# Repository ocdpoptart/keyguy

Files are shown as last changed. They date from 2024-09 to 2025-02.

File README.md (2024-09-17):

This entire thing has been a project to make a keyboard that had every quality I liked in one except for having a usb hub (I figured I could make one of those later). Unfortunately this entire thing has spiraled out of control and now I have even learned how to use this silly thing called GitHub. I want to cry.

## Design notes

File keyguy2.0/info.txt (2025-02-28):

so after taking forever to finish the keyboard you succeeded

now the issue is that it was flawed from the start now onto the changes

X (wrong from the start only needed to change the pin) - first a different oled (this is because the nice view steals the rgb pin) [there is an example of this in your saved bookmarks]
X - next change the led tolerances because depending on the saulder job the keys can hit them (push them up like half a mil)
X - maybe add more with use of the keyboard get used to it and if there are complaints then they can be corrected for v2
- I like the height of the overall product as it is in v1, so raise just the outer walls of the case no need to change the thickness of bottom plate or the height of the standoffs, this raised outer wall will allow the plate to fit in snug and not be a nuicense while protecting the board more (this will force you to have to make case cutouts for the usbc port and the pwr/rst switch, hurray blender or freecad) [18mm height for the outer wall]
-

COMPLETELY UNUSABLE ACCIDENTLY WIRED 4 KEYS EXACTLY THE SAME LIKE AN IDIOT

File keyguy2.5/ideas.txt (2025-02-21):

IDEAS:
    -holes/space for screen niceview screen protector
    -depending on how you like the 2.0 case possibly make adjustments to allow fit with the screen protector (and better protection of keys and pcb) [you also bought batteries too big for the case so if you don't like the case size which you may not you can adjust to accomadate them]

TO ADD:

DONE:
    - change mounting hole sizes from m2.5 to m2
    - correct the led matrix so that they are all connected to the pin and work properly made that mistake again with these fucking leds

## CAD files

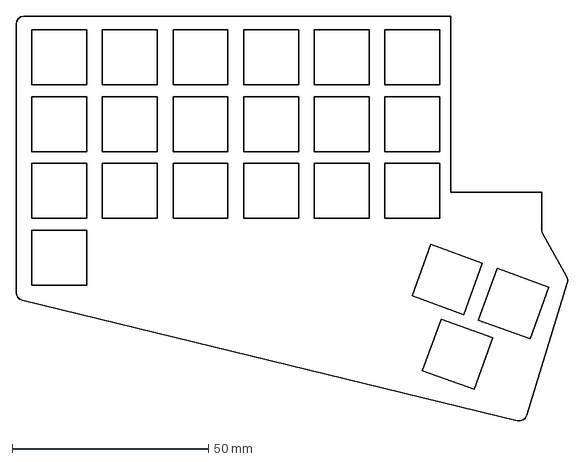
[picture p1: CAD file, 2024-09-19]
keyguy2.0/output/outlines/xlboard_cutout.dxf
140.6 x 103.3 mm

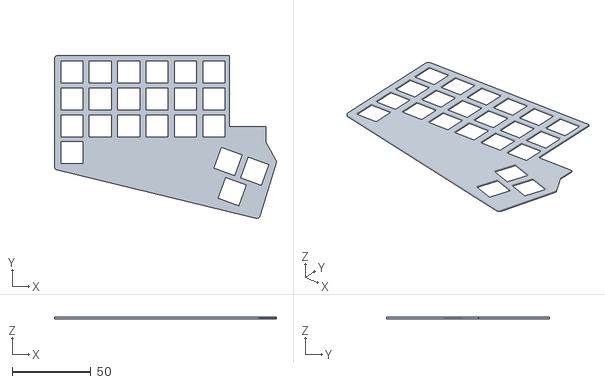
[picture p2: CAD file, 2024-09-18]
v3all/goodplate2.stl
140.6 x 103.1 x 1.00

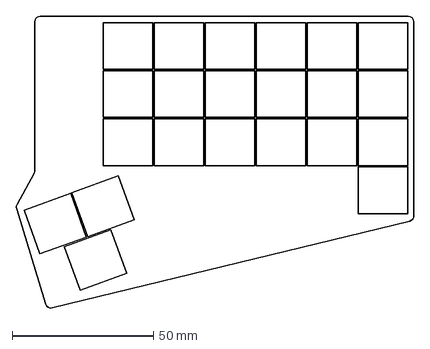
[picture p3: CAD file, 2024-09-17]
v3all/output/outlines/xlboard_cutout2.dxf
140.6 x 103.3 mm

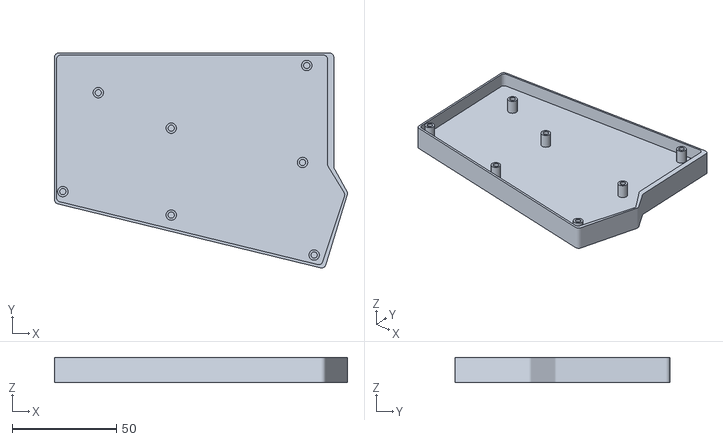
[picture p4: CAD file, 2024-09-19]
v4all/case.stl
140.6 x 103.1 x 12.0

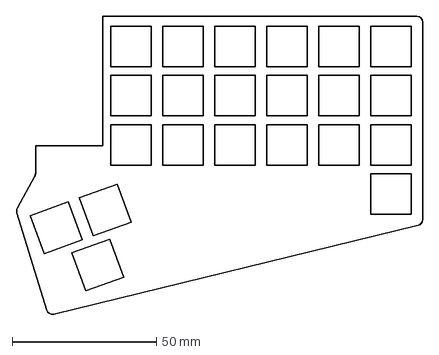
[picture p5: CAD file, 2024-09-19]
keyguy2.0/output/outlines/xlboard2_cutout.dxf
140.6 x 103.3 mm

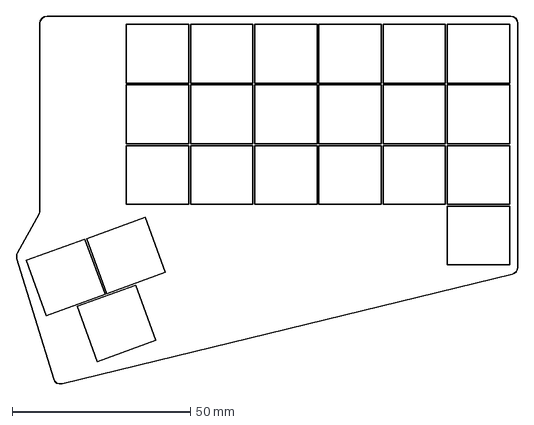
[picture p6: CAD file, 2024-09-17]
v2all/outlines/xlboard_cutout2.dxf
140.6 x 103.3 mm

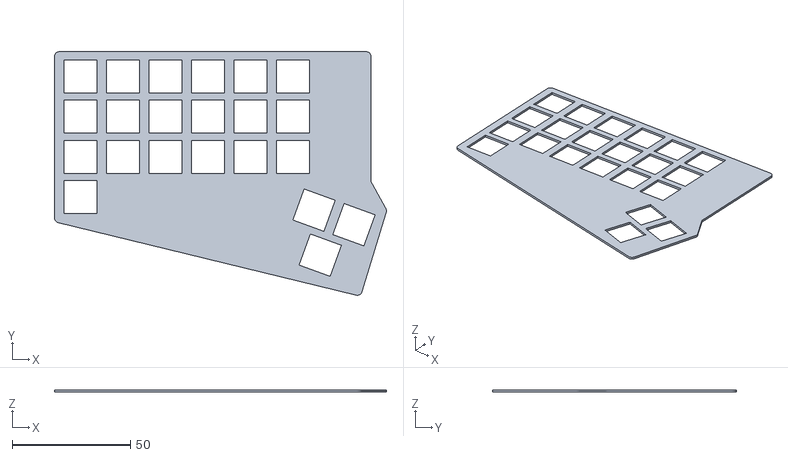
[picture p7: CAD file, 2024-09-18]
v3all/goodplate.stl
140.6 x 103.1 x 1.00

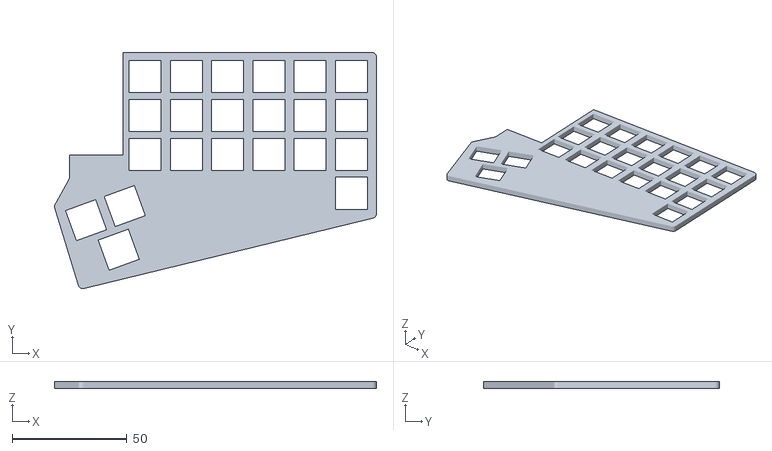
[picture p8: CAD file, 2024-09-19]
v4all/plate2.stl
140.6 x 103.1 x 3.00

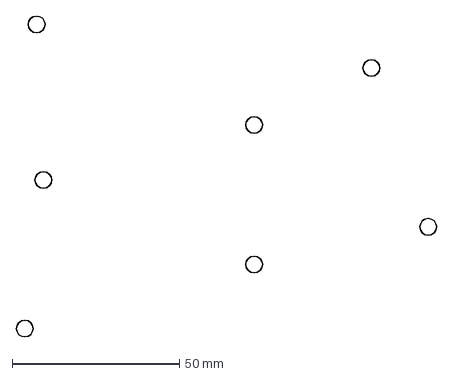
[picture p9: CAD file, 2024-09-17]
keyguy2.0/output/outlines/standoff2.dxf
125.6 x 95.9 mm

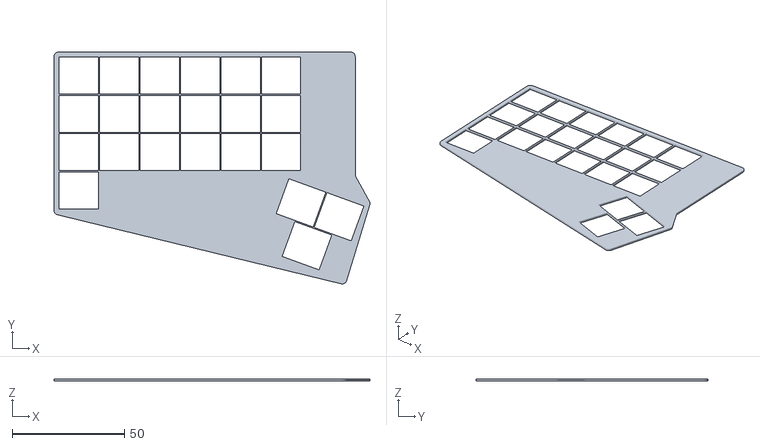
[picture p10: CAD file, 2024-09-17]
v3all/plate.stl
140.6 x 103.1 x 1.00

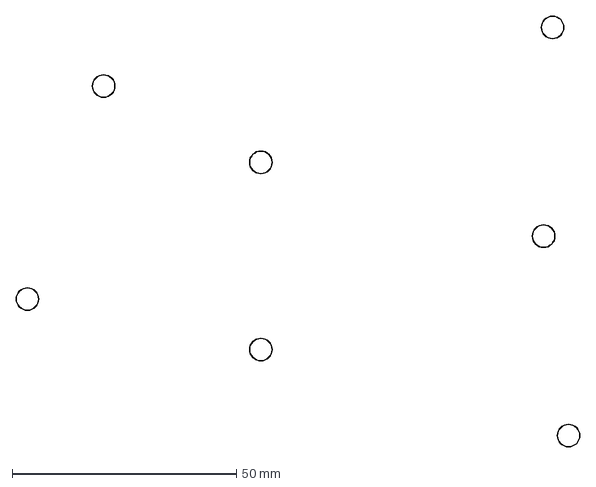
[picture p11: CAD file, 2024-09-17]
keyguy2.0/output/outlines/standoff.dxf
125.6 x 95.9 mm

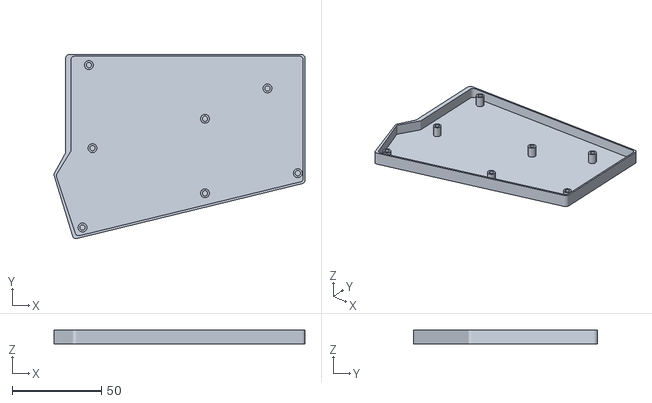
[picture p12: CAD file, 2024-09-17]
v3all/case2.stl
140.6 x 103.1 x 8.00

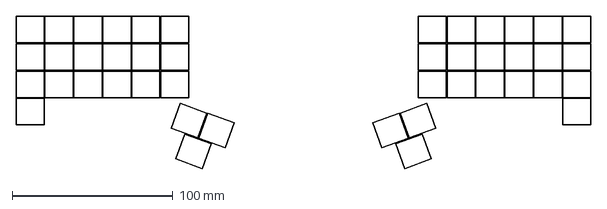
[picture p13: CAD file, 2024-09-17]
keyguy2.0/output/outlines/keys.dxf
357.5 x 94.6 mm

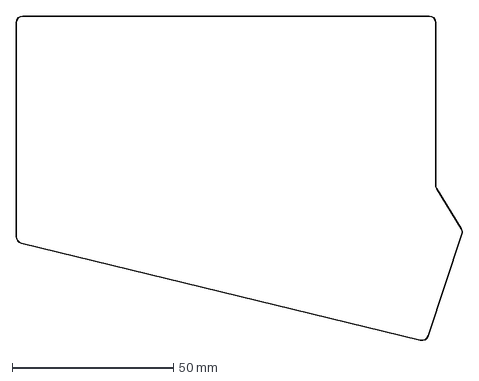
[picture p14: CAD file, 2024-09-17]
keyguy2.0/output/outlines/board.dxf
138.3 x 100.7 mm

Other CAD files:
v4all/case2.stl
v4all/plate.stl
v3all/case.stl
keyguy2.0/output/outlines/combo.dxf
keyguy2.0/output/outlines/board2.dxf
keyguy2.0/output/outlines/combo2.dxf
keyguy2.0/output/outlines/mounting.dxf
keyguy2.0/output/outlines/mounting2.dxf
keyguy2.0/output/outlines/raw.dxf
keyguy2.0/output/outlines/xlboard.dxf
keyguy2.0/output/outlines/xlboard2.dxf
v1outlines/board.dxf
v1outlines/combo.dxf
v1outlines/keys.dxf
v1outlines/raw.dxf
v2all/outlines/board.dxf
v2all/outlines/board2.dxf
v2all/outlines/combo.dxf
v2all/outlines/combo2.dxf
v2all/outlines/keys.dxf
v2all/outlines/mounting.dxf
v2all/outlines/mounting2.dxf
v2all/outlines/raw.dxf
v2all/outlines/standoff.dxf
v2all/outlines/standoff2.dxf
v2all/outlines/xlboard.dxf
v2all/outlines/xlboard2.dxf
v2all/outlines/xlboard_cutout.dxf

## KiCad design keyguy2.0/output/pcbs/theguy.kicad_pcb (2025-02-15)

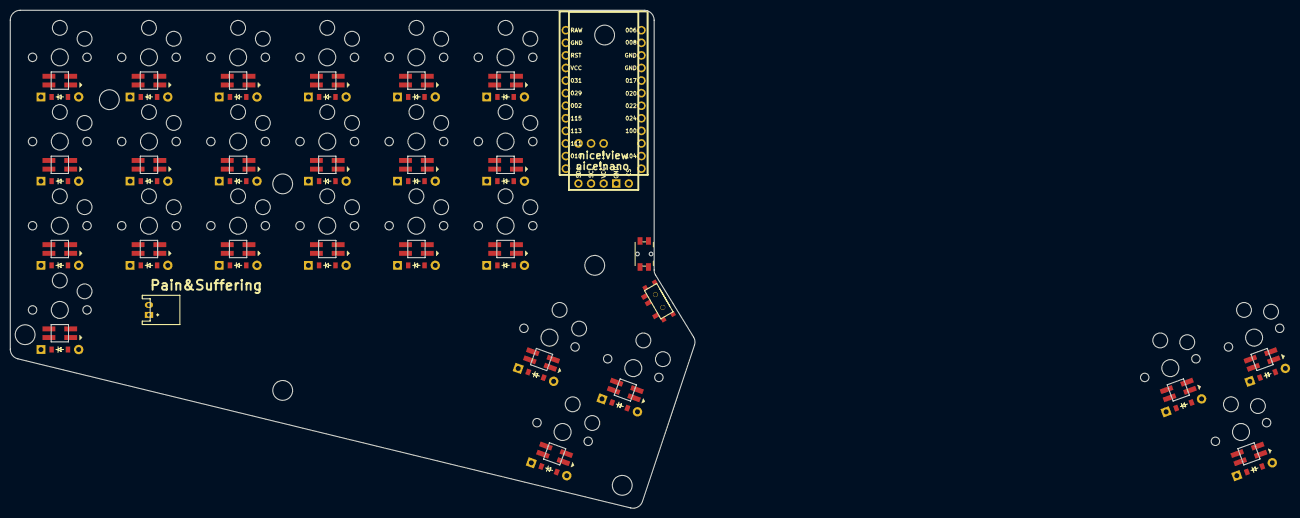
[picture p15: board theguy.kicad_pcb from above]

Board: 2 copper layers, 138.2 x 100.5 mm, 80 parts (0 on the bottom side), 64 nets, no tracks yet.

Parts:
B1: Panasonic_EVQPUL_EVQPUC
D1, D2, D3, D4, D5, D6, D7, D8, D9, D10, D11, D12, D13, D14, D15, D16, D17, D18, D19, D20, D21, D22, D23, D24, D25: ComboDiode
JST1: JST_PH_S2B-PH-K_02x2.00mm_Angled
LED1, LED2, LED3, LED4, LED5, LED6, LED7, LED8, LED9, LED10, LED11, LED12, LED13, LED14, LED15, LED16, LED17, LED18, LED19, LED20, LED21, LED22, LED23, LED24, LED25: WS2812B
MCU1: nice_nano
S1, S2, S3, S4, S5, S6, S7, S8, S9, S10, S11, S12, S13, S14, S15, S16, S17, S18, S19, S20, S21, S22, S23, S24, S25: PG1350
T1: SPDT_C128955
niceView1: niceView; niceView_headers

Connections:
GND: B1.1, JST1.2, LED1.3, LED2.3, LED3.3, LED4.3, LED5.3, LED6.3, LED7.3, LED8.3, LED9.3, LED10.3, LED11.3, LED12.3, LED13.3, LED14.3, LED15.3, LED16.3, LED17.3, LED18.3, LED19.3, LED20.3, LED21.3, LED22.3, LED23.3, LED24.3, LED25.3, MCU1.3, MCU1.4, MCU1.23, niceView1.2
P002: MCU1.18, S8.1, S9.1, S10.1
P006: LED22.4, LED25.4, MCU1.1
P009: D3.1, D6.1, D9.1, D12.1, D15.1, D18.1, MCU1.13
P010: D4.1, D7.1, D10.1, D13.1, D16.1, D19.1, MCU1.14
P017: MCU1.5, niceView1.5
P020: MCU1.6, niceView1.4
P022: MCU1.7, niceView1.1
P029: MCU1.19, S5.1, S6.1, S7.1
P031: MCU1.20, S1.1, S2.1, S3.1, S4.1
P104: D2.1, D5.1, D8.1, D11.1, D14.1, D17.1, D20.1, D21.1, D23.1, D24.1, MCU1.11
P106: D1.1, D22.1, D25.1, MCU1.12
P111: MCU1.15, S17.1, S18.1, S19.1, S21.1, S22.1, S24.1, S25.1
P113: MCU1.16, S14.1, S15.1, S16.1, S20.1, S23.1
P115: MCU1.17, S11.1, S12.1, S13.1
RAW: MCU1.24, T1.2
RST: B1.2, MCU1.22
VCC: LED1.1, LED2.1, LED3.1, LED4.1, LED5.1, LED6.1, LED7.1, LED8.1, LED9.1, LED10.1, LED11.1, LED12.1, LED13.1, LED14.1, LED15.1, LED16.1, LED17.1, LED18.1, LED19.1, LED20.1, LED21.1, LED22.1, LED23.1, LED24.1, LED25.1, MCU1.21, niceView1.3
extra_cluster: D22.2, S22.2
hell_bottom: D2.2, S2.2
hell_home: D3.2, S3.2
hell_last: D1.2, S1.2
hell_top: D4.2, S4.2
index_bottom: D14.2, S14.2
index_home: D15.2, S15.2
index_top: D16.2, S16.2
inner_bottom: D17.2, S17.2
inner_home: D18.2, S18.2
inner_top: D19.2, S19.2
layer_cluster: D20.2, S20.2
middle_bottom: D11.2, S11.2
middle_home: D12.2, S12.2
middle_top: D13.2, S13.2
mirror_extra_cluster: D25.2, S25.2
mirror_layer_cluster: D23.2, S23.2
mirror_space_cluster: D24.2, S24.2
pinky_bottom: D5.2, S5.2
pinky_home: D6.2, S6.2
pinky_top: D7.2, S7.2
pos: JST1.1, T1.1
rgb_matrix_hell_bottom: LED2.4, LED3.2
rgb_matrix_hell_home: LED3.4, LED4.2
rgb_matrix_hell_last: LED1.4, LED2.2
rgb_matrix_hell_top: LED4.4, LED7.2
rgb_matrix_index_bottom: LED14.4, LED15.2, LED20.2, LED23.2
rgb_matrix_index_home: LED15.4, LED16.2
rgb_matrix_index_top: LED16.4, LED19.2
rgb_matrix_inner_bottom: LED17.4, LED22.2, LED25.2
rgb_matrix_inner_home: LED17.2, LED18.4
rgb_matrix_inner_top: LED18.2, LED19.4
rgb_matrix_middle_home: LED11.2, LED12.4
rgb_matrix_middle_top: LED12.2, LED13.4
rgb_matrix_pinky_bottom: LED5.4, LED8.2
rgb_matrix_pinky_home: LED5.2, LED6.4
rgb_matrix_pinky_top: LED6.2, LED7.4
rgb_matrix_ring_bottom: LED8.4, LED9.2
rgb_matrix_ring_home: LED9.4, LED10.2
rgb_matrix_ring_top: LED10.4, LED13.2
rgb_thumbs_layer_cluster: LED20.4, LED21.2, LED23.4, LED24.2
rgb_thumbs_space_cluster: LED14.2, LED21.4, LED24.4
ring_bottom: D8.2, S8.2
ring_home: D9.2, S9.2
ring_top: D10.2, S10.2
space_cluster: D21.2, S21.2

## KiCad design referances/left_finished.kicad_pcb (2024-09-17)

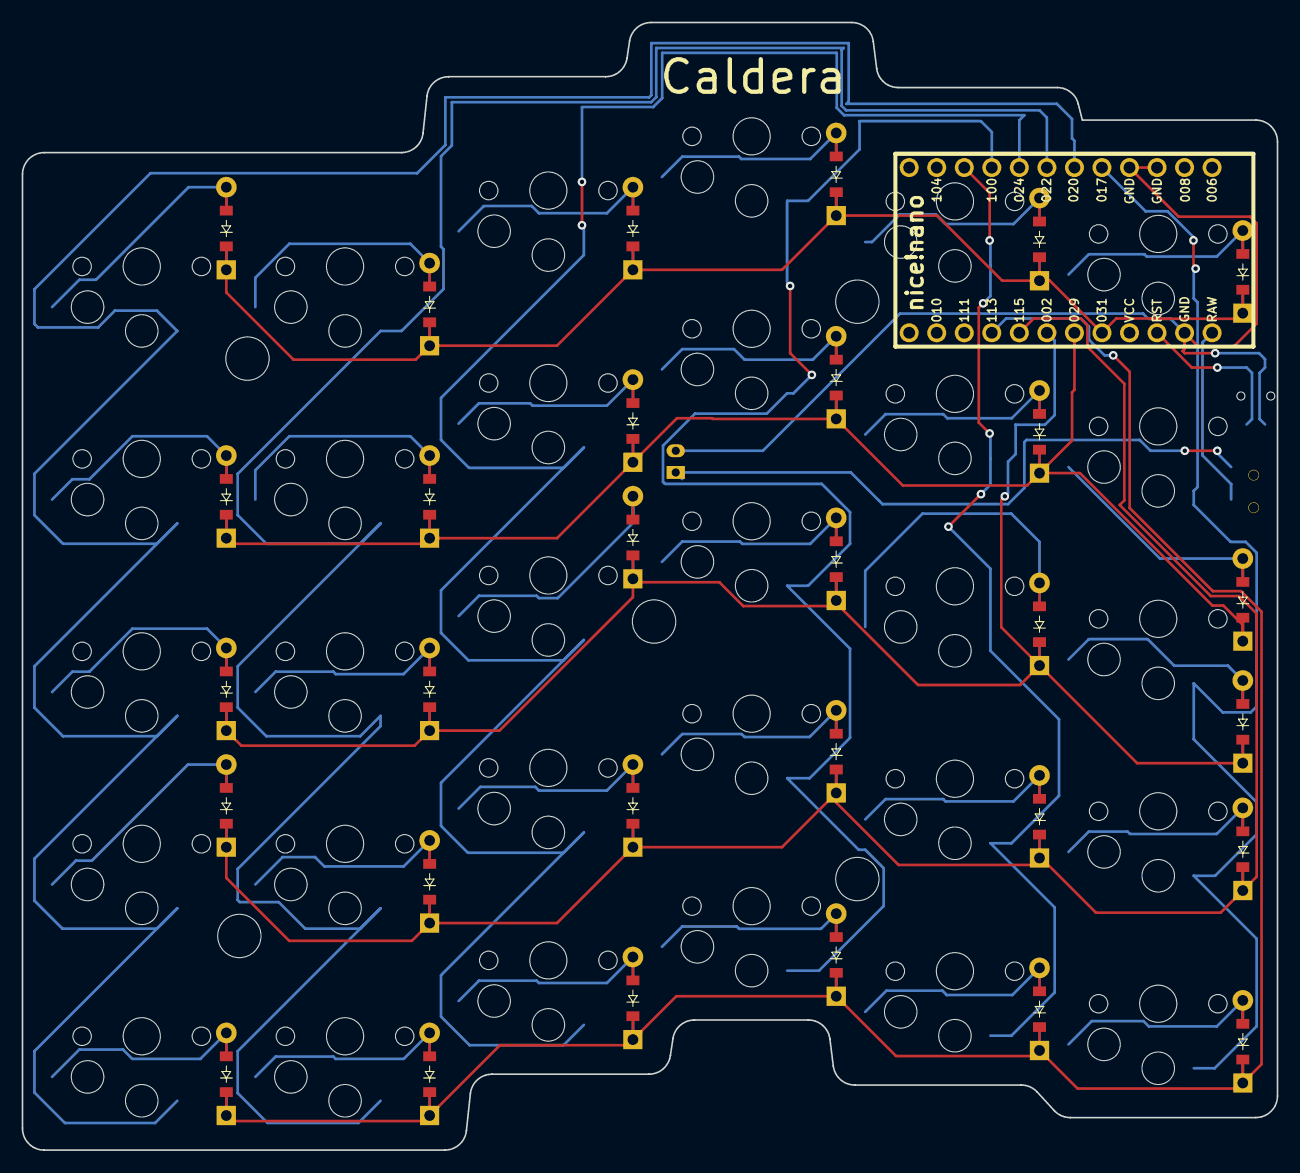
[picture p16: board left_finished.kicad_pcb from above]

Board: 2 copper layers, 115.8 x 104.0 mm, 64 parts (0 on the bottom side), 45 nets.

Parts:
B1: Panasonic_EVQPUL_EVQPUC
D1, D2, D3, D4, D5, D6, D7, D8, D9, D10, D11, D12, D13, D14, D15, D16, D17, D18, D19, D20, D21, D22, D23, D24, D25, D26, D27, D28, D29, D30: ComboDiode
JST1: JST_PH_S2B-PH-K_02x2.00mm_Angled
MCU1: nice_nano
S1, S2, S3, S4, S5, S6, S7, S8, S9, S10, S11, S12, S13, S14, S15, S16, S17, S18, S19, S20, S21, S22, S23, S24, S25, S26, S27, S28, S29, S30: PG1350
T1: SPDT_C128955

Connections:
GND: B1.1, JST1.2, MCU1.3, MCU1.4, MCU1.23
P002: D2.1, D6.1, D14.1, D18.1, D25.1, D28.1, MCU1.18
P011: MCU1.10, S21.1, S22.1, S23.1, S24.1, S25.1
P017: MCU1.5, S26.1, S27.1, S28.1, S29.1, S30.1
P020: MCU1.6, S1.1, S2.1, S3.1, S4.1, S5.1
P022: MCU1.7, S6.1, S7.1, S8.1, S9.1, S10.1
P024: MCU1.8, S11.1, S12.1, S13.1, S14.1, S15.1
P029: D3.1, D7.1, D11.1, D19.1, D24.1, D30.1, MCU1.19
P031: D8.1, D12.1, D15.1, D20.1, D23.1, D27.1, MCU1.20
P100: MCU1.9, S16.1, S17.1, S18.1, S19.1, S20.1
P113: D1.1, D4.1, D9.1, D16.1, D21.1, D29.1, MCU1.16
P115: D5.1, D10.1, D13.1, D17.1, D22.1, D26.1, MCU1.17
RAW: MCU1.24, T1.2
RST: B1.2, MCU1.22
fifth_bottom: D17.2, S22.2
fifth_home: D18.2, S23.2
fifth_mod: D16.2, S21.2
fifth_num: D20.2, S25.2
fifth_top: D19.2, S24.2
first_bottom: D26.2, S2.2
first_home: D2.2, S3.2
first_mod: D1.2, S1.2
first_num: D27.2, S5.2
first_top: D3.2, S4.2
fourth_bottom: D13.2, S17.2
fourth_home: D14.2, S18.2
fourth_mod: D29.2, S16.2
fourth_num: D15.2, S20.2
fourth_top: D30.2, S19.2
pos: JST1.1, T1.1
second_bottom: D5.2, S7.2
second_home: D6.2, S8.2
second_mod: D4.2, S6.2
second_num: D8.2, S10.2
second_top: D7.2, S9.2
sixth_bottom: D22.2, S27.2
sixth_home: D25.2, S28.2
sixth_mod: D21.2, S26.2
sixth_num: D23.2, S30.2
sixth_top: D24.2, S29.2
third_bottom: D10.2, S12.2
third_home: D28.2, S13.2
third_mod: D9.2, S11.2
third_num: D12.2, S15.2
third_top: D11.2, S14.2

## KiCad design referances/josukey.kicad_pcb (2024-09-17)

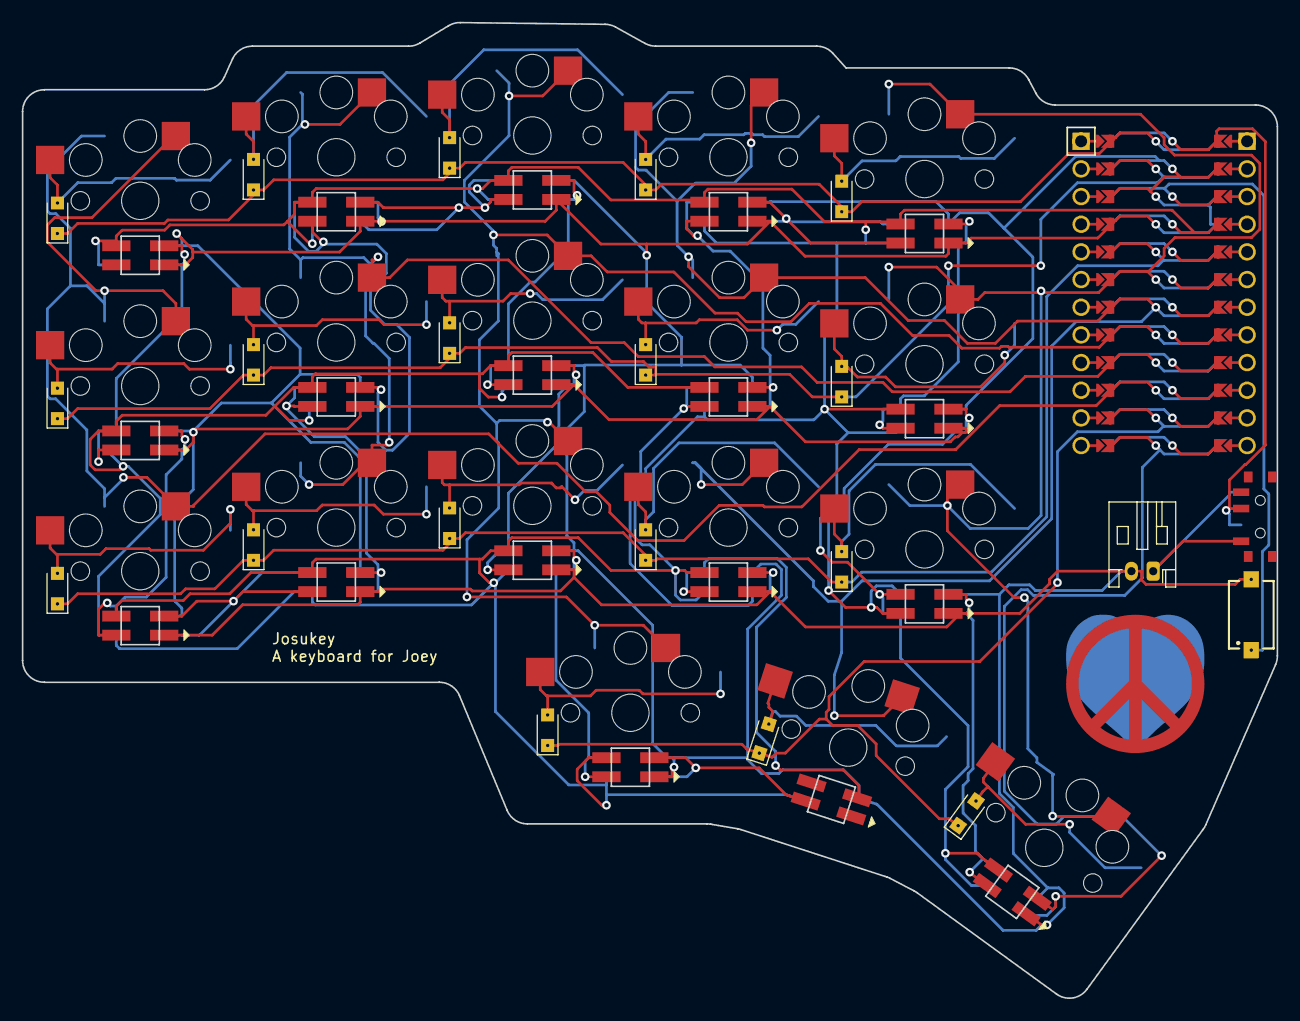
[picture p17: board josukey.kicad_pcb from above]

Board: 2 copper layers, 115.2 x 89.6 mm, 58 parts (0 on the bottom side), 50 nets.

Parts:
D1, D2, D3, D4, D5, D6, D7, D8, D9, D10, D11, D12, D13, D14, D15, D16, D17, D18: Nexperia_CFP3_SOD-123W
LED1, LED2, LED3, LED4, LED5, LED6, LED7, LED8, LED9, LED10, LED11, LED12, LED13, LED14, LED15, LED16, LED17, LED18: WS2812B
MCU1: ProMicro
S1, S2, S3, S4, S5, S6, S7, S8, S9, S10, S11, S12, S13, S14, S15, S16, S17, S18: PG1350
S19: 434121025816
T1: SW_SPDT_PCM12
_1: JST_PH_S2B-PH-K_1x02_P2.00mm_Horizontal

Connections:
GND: LED1.3, LED2.3, LED3.3, LED4.3, LED5.3, LED6.3, LED7.3, LED8.3, LED9.3, LED10.3, LED11.3, LED12.3, LED13.3, LED14.3, LED15.3, LED16.3, LED17.3, LED18.3, MCU1.2, MCU1.21, MCU1.22, S19.2, _1.2
P0: D2.1, D5.1, D8.1, D11.1, D14.1, MCU1.23
P1: D3.1, D6.1, D9.1, D12.1, D15.1, MCU1.24
P2: D1.1, D4.1, D7.1, D10.1, D13.1, MCU1.20
P3: MCU1.19, S13.1, S14.1, S15.1, S18.1
P4: MCU1.18, S10.1, S11.1, S12.1, S17.1
P5: MCU1.17, S7.1, S8.1, S9.1, S16.1
P6: MCU1.16, S4.1, S5.1, S6.1
P7: MCU1.15, S1.1, S2.1, S3.1
P8: D16.1, D17.1, D18.1, MCU1.14
P9: LED18.4, MCU1.13
RAW: MCU1.1, T1.2
RST: MCU1.3, S19.1
VCC: LED1.1, LED2.1, LED3.1, LED4.1, LED5.1, LED6.1, LED7.1, LED8.1, LED9.1, LED10.1, LED11.1, LED12.1, LED13.1, LED14.1, LED15.1, LED16.1, LED17.1, LED18.1, MCU1.4
main_index_bottom: D10.2, S10.2
main_index_home: D11.2, S11.2
main_index_top: D12.2, S12.2
main_inner_bottom: D13.2, S13.2
main_inner_home: D14.2, S14.2
main_inner_top: D15.2, S15.2
main_middle_bottom: D7.2, S7.2
main_middle_home: D8.2, S8.2
main_middle_top: D9.2, S9.2
main_pinky_bottom: D1.2, S1.2
main_pinky_home: D2.2, S2.2
main_pinky_top: D3.2, S3.2
main_ring_bottom: D4.2, S4.2
main_ring_home: D5.2, S5.2
main_ring_top: D6.2, S6.2
pos: T1.1, _1.1
rgb_main_index_bottom: LED10.4, LED11.2
rgb_main_index_home: LED11.4, LED12.2
rgb_main_index_top: LED12.4, LED15.2
rgb_main_inner_bottom: LED13.4, LED18.2
rgb_main_inner_home: LED13.2, LED14.4
rgb_main_inner_top: LED14.2, LED15.4
rgb_main_middle_bottom: LED7.4, LED16.2
rgb_main_middle_home: LED7.2, LED8.4
rgb_main_middle_top: LED8.2, LED9.4
rgb_main_pinky_bottom: LED1.4, LED4.2
rgb_main_pinky_home: LED1.2, LED2.4
rgb_main_pinky_top: LED2.2, LED3.4
rgb_main_ring_bottom: LED4.4, LED5.2
rgb_main_ring_home: LED5.4, LED6.2
rgb_main_ring_top: LED6.4, LED9.2
rgb_thumb_home_home: LED10.2, LED17.4
rgb_thumb_inner_home: LED16.4, LED17.2
thumb_home_home: D17.2, S17.2
thumb_inner_home: D16.2, S16.2
thumb_outer_home: D18.2, S18.2

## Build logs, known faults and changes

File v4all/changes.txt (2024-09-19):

this should be an almost complete version

-everything about the plate was corrected
-the case is now a proper size
    *still want to correct the holes and standoffs so the board can be in the case instead of on top
-the board should be complete will depend on if leds work

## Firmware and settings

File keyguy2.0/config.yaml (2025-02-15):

units:
  # Proxy Spacing Variables
  kx: cx
  ky: cy
  # Padding Variables
  px: kx + 2
  py: ky + 2
  # More Padding Variables
  dpx: kx + 4
  dpy: ky + 4
  # M2 Screw Inserts
  screwSize: 1.5
  standoffSize: 2.5

points:
  zones:
    matrix:
          # Fix placement on KiCAD sheet.
      anchor:
        shift: [70, -100]
      key:
        padding: 1ky
        spread: 1kx
      rows:
        last.row_net: P106
        bottom.row_net: P104
        home.row_net: P009
        top.row_net: P010
      columns:
        hell:
          key.column_net: P031
          rows:
            last:
              led_in: "rgb_{{name}}"
            bottom:
              led_in: "rgb_{{name}}"
              led_out: rgb_matrix_hell_last
            home:
              led_in: "rgb_{{name}}"
              led_out: rgb_matrix_hell_bottom
            top:
              led_in: "rgb_{{name}}"
              led_out: rgb_matrix_hell_home
        pinky:
          key.column_net: P029
          rows:
            last.skip: true
            bottom:
              led_in: "rgb_{{name}}"
              led_out: rgb_matrix_pinky_home
            home:
              led_in: "rgb_{{name}}"
              led_out: rgb_matrix_pinky_top
            top:
              led_in: "rgb_{{name}}"
              led_out: rgb_matrix_hell_top
        ring:
          key.column_net: P002
          rows:
            last.skip: true
            bottom:
              led_in: "rgb_{{name}}"
              led_out: rgb_matrix_pinky_bottom
            home:
              led_in: "rgb_{{name}}"
              led_out: rgb_matrix_ring_bottom
            top:
              led_in: "rgb_{{name}}"
              led_out: rgb_matrix_ring_home
        middle:
          key.column_net: P115
          rows:
            last.skip: true
            bottom:
              led_in: "rgb_{{name}}"
              led_out: rgb_matrix_middle_home
            home:
              led_in: "rgb_{{name}}"
              led_out: rgb_matrix_middle_top
            top:
              led_in: "rgb_{{name}}"
              led_out: rgb_matrix_ring_top
        index:
          key.column_net: P113
          rows:
            last.skip: true
            bottom:
              led_in: "rgb_{{name}}"
              led_out: rgb_thumbs_space_cluster
            home:
              led_in: "rgb_{{name}}"
              led_out: rgb_matrix_index_bottom
            top:
              led_in: "rgb_{{name}}"
              led_out: rgb_matrix_index_home
        inner:
          key.column_net: P111
          rows:
            last.skip: true
            bottom:
              led_in: "rgb_{{name}}"
              led_out: rgb_matrix_inner_home
            home:
              led_in: "rgb_{{name}}"
              led_out: rgb_matrix_inner_top
            top:
              led_in: "rgb_{{name}}"
              led_out: rgb_matrix_index_top
    thumbs:
      key:
        padding: 1ky
        spread: 1kx
      anchor:
        ref: matrix_inner_bottom
        shift: [ 2 , -2 ]
      columns:
        layer:
          key:
            column_net: P113
            splay: -20
            led_in: "rgb_{{name}}"
            led_out: rgb_matrix_index_bottom
        space:
          key:
            column_net: P111
            led_in: "rgb_{{name}}"
            led_out: rgb_thumbs_layer_cluster
      rows:
        cluster:
          shift: [ .75kx , -1ky]
          row_net: P104
    ethumb:
      key:
        padding: 1ky
        spread: 1kx
      anchor:
        ref: thumbs_layer_cluster
      columns:
        extra:
          key:
            column_net: P111
            width: 1.5kx
            led_in: P006
            led_out: rgb_matrix_inner_bottom
      rows:
        cluster:
          shift: [ .5kx, -1ky ]
          row_net: P106
  #Kill me slowly
  mirror:
    ref: matrix_inner_home
    distance: 160
outlines:
  raw:
    - what: rectangle
      where: true
      size: [ px, py ]
  keys:
    - what: rectangle
      where: true
      size: [kx-0.5,ky-.5]
  board:
    - what: polygon
      operation: stack
      points:
        - ref: matrix_hell_top
          shift: [ -.5px , .5py ]
        - ref: matrix_inner_top
          shift: [ 1.5px , .5py ]
        - ref: matrix_inner_bottom
          shift: [ 1.5px , -.5py ]
        - ref: thumbs_space_cluster
          shift: [ .5px , .5py ]
        - ref: ethumb_extra_cluster
          shift: [ 1px , -.5py ]
        - ref: matrix_hell_last
          shift: [ -.5px , -.5py ]
      fillet: 2
  board2:
    - what: polygon
      operation: stack
      points:
        - ref: mirror_matrix_hell_top
          shift: [ -.5px , .5py ]
        - ref: mirror_matrix_inner_top
          shift: [ 1.5px , .5py ]
        - ref: mirror_matrix_inner_bottom
          shift: [ 1.5px , -.5py ]
        - ref: mirror_thumbs_space_cluster
          shift: [ .5px , .5py ]
        - ref: mirror_ethumb_extra_cluster
          shift: [ 1px , -.5py ]
        - ref: mirror_matrix_hell_last
          shift: [ -.5px , -.5py ]
      fillet: 2
  xlboard:
    - what: polygon
      operation: stack
      points:
        - ref: matrix_hell_top
          shift: [ -.5dpx , .5dpy ]
        - ref: matrix_inner_top
          shift: [ 1.5dpx , .5dpy ]
        - ref: matrix_inner_bottom
          shift: [ 1.5dpx , -.5dpy ]
        - ref: thumbs_space_cluster
          shift: [ .5dpx , .5dpy ]
        - ref: ethumb_extra_cluster
          shift: [ 1dpx , -.5dpy ]
        - ref: matrix_hell_last
          shift: [ -.5dpx , -.5dpy ]
      fillet: 2
  xlboard2:
    - what: polygon
      operation: stack
      points:
        - ref: mirror_matrix_hell_top
          shift: [ -.5dpx , .5dpy ]
        - ref: mirror_matrix_inner_top
          shift: [ 1.5dpx , .5dpy ]
        - ref: mirror_matrix_inner_bottom
          shift: [ 1.5dpx , -.5dpy ]
        - ref: mirror_thumbs_space_cluster
          shift: [ .5dpx , .5dpy ]
        - ref: mirror_ethumb_extra_cluster
          shift: [ 1dpx , -.5dpy ]
        - ref: mirror_matrix_hell_last
          shift: [ -.5dpx , -.5dpy ]
      fillet: 2
  xlboard_cutout:
    - name: xlboard
    - operation: subtract
      where: /^matrix_|thumbs_|ethumb_.*/
      what: rectangle
      size: [ 14 , 14 ]
    - operation: subtract
      where:
          ref: matrix_inner_bottom
          shift: [1.25kx , 1.3ky]
          rotate: -90
      what: rectangle
      size: [ 2.5kx , 1.5ky ]
  xlboard2_cutout:
    - name: xlboard2
    - operation: subtract
      where: /^mirror_matrix_|thumbs_|ethumb_.*/
      what: rectangle
      size: [ 14 , 14 ]
    - operation: subtract
      where:
          ref: mirror_matrix_inner_bottom
          shift: [1.25kx , 1.3ky]
          rotate: -90
      what: rectangle
      size: [ 2.5kx , 1.5ky ]
  mounting:
    - what: circle
      radius: screwSize
      where:
        ref: ethumb_extra_cluster
        shift: [ 15  , -6 ]
    - what: circle
      radius: screwSize
      where:
          ref: matrix_hell_last
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

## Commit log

2024-09-17 pain and suffering
    [board.dxf, board2.dxf, case.stl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]
2024-09-18 changing things again
    [goodplate.stl]
2024-09-18 changing things again 2.0
    [goodplate2.stl]
2024-09-19 gonna need to buy a 3d printer at this rate
    [board.dxf, board2.dxf, case.stl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]
2025-02-13 2.0 done?
    [board.dxf, board2.dxf, combo.dxf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]
2025-02-15 2.0 done for real this time
    [theguy.kicad_pcb, theguy2.kicad_pcb]
2025-02-15 pcbs wired
    [theguy.kicad_pcb, theguy2.kicad_pcb]
2025-02-15 pcb files ready to be made
    [theguy-B_Cu.gbr, theguy-B_Mask.gbr, theguy-B_Paste.gbr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]
2025-02-16 added a 2.5 for future minor improvements such as correcting screwsize from m2.5 to m2
    [theguy.kicad_pcb, theguy2.kicad_pcb]
2025-02-16 corrected config so that case has proper depth for battery
    [config.yaml]
2025-02-19 corrected mounting
2025-02-21 fixed leds so all connected and work sad i already sent out 2.0 pcb for production where more than half won't work
    [config.yaml]
2025-02-28 corrected 2.5 so we don't have repeat keys like 2.0, still don't know if leds will work so chill for a bit
    [config.yaml]
